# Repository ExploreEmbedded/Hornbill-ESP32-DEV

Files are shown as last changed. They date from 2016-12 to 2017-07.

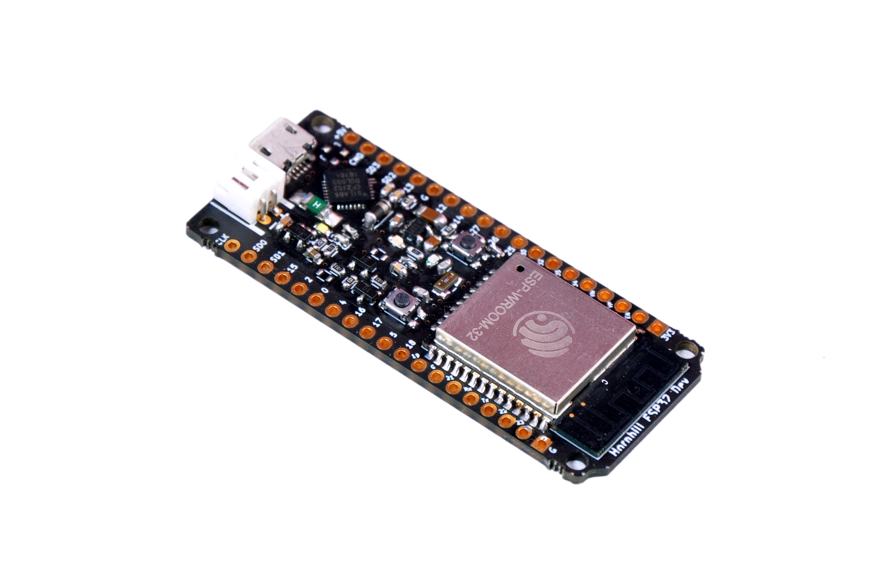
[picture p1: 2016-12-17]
Others/images/Hornbill_02.JPG

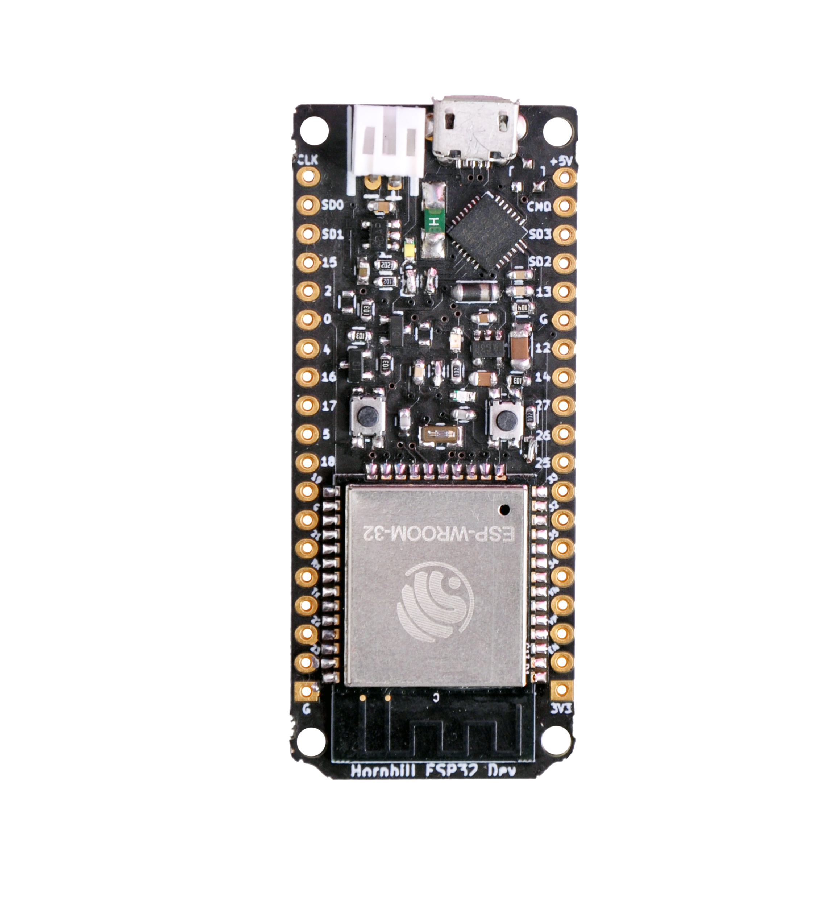
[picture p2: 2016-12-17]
Others/images/Hornbill_01.JPG

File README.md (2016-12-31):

# Hornbill-ESP32-DEV
Affordable, Rugged, Secure and Open Hardware for battery powered connected things with ESP32.
Hornbill ESP32 Dev
Hornbill is based on ESP32. A single chip solution  with  dual core high speed processors, numerous peripherals and built in WiFi and Bluetooth (Classic as well as BLE). Hornbill  ESP32 Dev board comes with built in single cell LiPo charger.  

The project Hornbill will also offer a rugged IP6 water/dust proof case and multipurpose baseboard to build rugged hardware. We will be writing numerous bare metal as well as Arduino tutorials to get you started. 

We believe IoT devices need to be more secure and we will work on providing end to end TLS1.2 encryption with major IoT cloud platforms. We will also on top build Open Source IoT frameworks to provide templates to run your own secure servers!  

We will be crowdfunding the project soon, signup at crowdsupply to get notified when the project goes live.

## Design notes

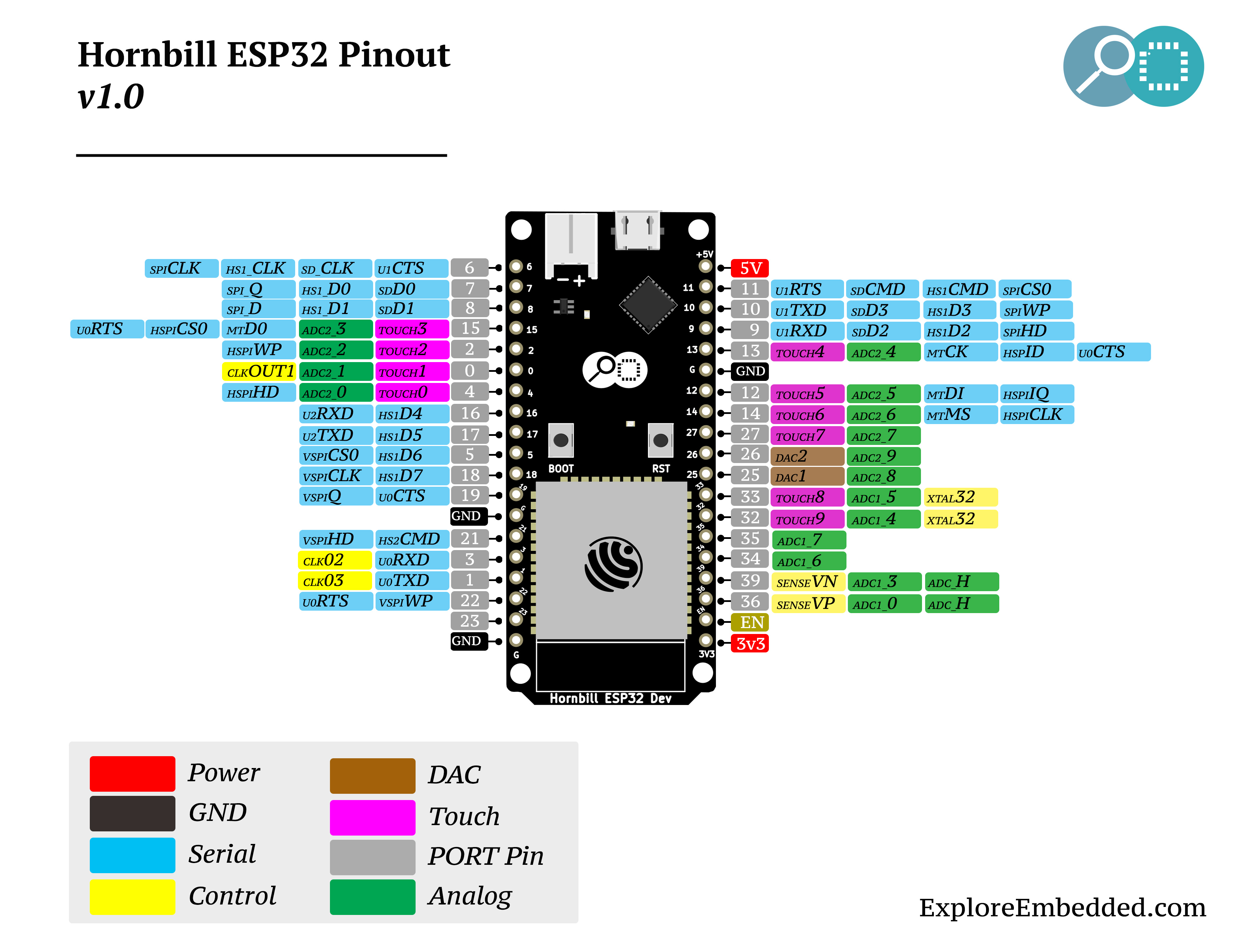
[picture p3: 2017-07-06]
pinout/v1.0/pinout_horbil_v1.0l.jpg

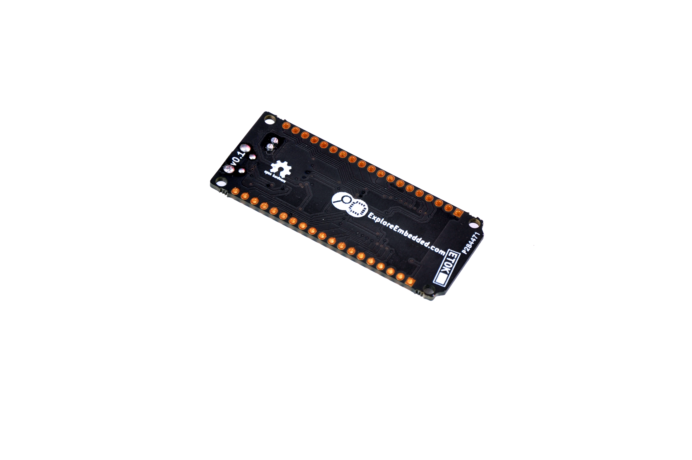
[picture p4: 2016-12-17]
Others/images/Hornbill_03.JPG

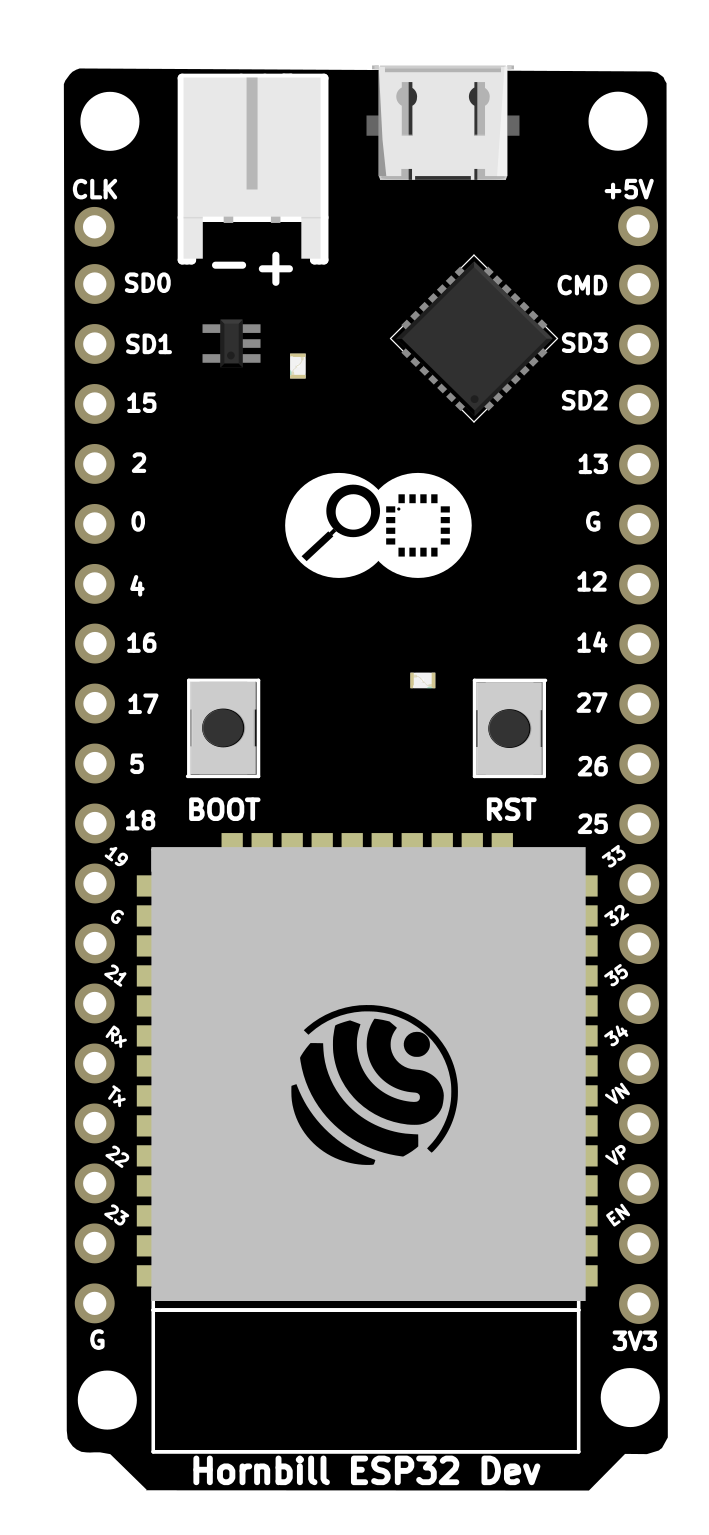
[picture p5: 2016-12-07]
Others/Fritzing/images/HornbillESP32_breadboard.png

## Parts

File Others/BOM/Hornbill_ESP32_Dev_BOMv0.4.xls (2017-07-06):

BOM
Product Name: Hornbill ESP32 Dev
Version:V0.4
Issue Date:13/06/2017
Quantity | 500
Item No. (??) | Reference Des (????) | Qty (??) | Catalog (??) | Part_Description (????) | Part_Value (???) | Part_Package (????) | Manufacturers Name (??????) | Manufacturers Part No. (??????) | Distributors Name (?????) | Distributors Part No. (?????)
1 | R1 | 1 | Resister | RES 100K OHM 1/4W 1% 0603 | 100K | 603
2 | R12,R8,R9,R10,R16,R17 | 6 | Resister | RES 0E OHM 1/4W 1% 0603 | 0E | 603
3 | R13 | 1 | Resister | RES 330E OHM 1/4W 1% 0603 | 330E | 603
4 | R2 | 1 | Resister | RES 2K OHM 1/4W 1% 0603 | 2K | 603
5 | R3,R4 | 2 | Resister | RES 1K OHM 1/4W 1% 0603 | 1K | 603
6 | R5,R6 | 2 | Resister | RES 12K OHM 1/4W 1% 0603 | 12K | 603
7 | R7,R11 | 2 | Resister | RES 10K OHM 1/4W 1% 0603 | 10K | 603
8 | C6,C1 | 2 | Capacitor | CAP CER 4.7UF 25V 10% X7R 0603 | 4.7uF | 603
9 | C2 | 1 | Capacitor | CAP CER 1UF 25V 10% X7R 0603 | 1uF | 603
10 | C5 | 1 | Capacitor | CAP CER 2.2UF 25V 10% X7R 0603 | 2.2uF | 603
11 | C7 | 1 | Capacitor | CAP Tantalum 100UF 25V 10% X7R 1206 | 100uF | 1206/Case 'A'
12 | C8,C10 | 2 | Capacitor | CAP CER 15pF 25V 10% X7R 0603 | 15pF | 603
13 | C9,C3,C4 | 3 | Capacitor | CAP CER 0.1uF 25V 10% X7R 0603 | 0.1uF | 603
14 | P1 | 1 | Connector | JST Connector, Right angle,2mm, White | JST | Surface Mount | JST (JAPAN SOLDERLESS TERMINALS) | S2B-PH-SM4-TB(LF)(SN) | element14 | 9492615
16 | U5 | 1 | IC | IC Bridge Controller CP2104 | CP2102 | QFN-24-1EP 4mmX4mm | Silicon Labs (http://www.digikey.com/en/supplier-centers/s/silicon-labs) | CP2104-F03-GM (http://www.digikey.com/product-detail/en/silicon-labs/CP2104-F03-GM/336-2008-5-ND/2486177) | Digikey | 336-2008-5-ND (http://www.digikey.com/product-detail/en/silicon-labs/CP2104-F03-GM/336-2008-5-ND/2486177)
17 | F1 | 1 | Fuse | Fuse,SMD,0.5A,Very fast blow | SMD Fuse | 1206 | LITTELFUSE (http://in.element14.com/littelfuse) | 0466.500NRHF | element14 | 2679301
18 | D2 | 1 | LED | LED, SMD, Yellow , 0603 | SMD LED | 603
19 | D3 | 1 | LED | LED, SMD, Red , 0603 | SMD LED | 603
20 | D4 | 1 | LED | LED, SMD, Blue , 0603 | SMD LED | 603
21 | IC1 | 1 | IC | Charger , MCP73831, 5pin,SMD | MCP73831 | SOT-23-5
22 | Q1 | 1 | IC | P Channel MOSFET, 3A, 3pin SMD | IRLML5203 | SOT-23
23 | U4 | 1 | Regulator | 3.3V Regulator, 0.6A, LDO | AP2112K-3.3V | SOT-23-5
24 | Q2,Q3 | 2 | Transistor | SMD Transistor, S8050 | S8050 | SOT-23
25 | CON1 | 1 | Connector | Micro USB CONN, 5 pin , | Micro USB
26 | D1 | 1 | Diode | Schottkey Diode | BAT20J |  | STMICROELECTRONICS | BAT20JFILM | element14 | 1467541
27 | SW1,SW2 | 2 | Switch | SWITCH TACTILE SPST-NO 50MA 32V | Tactile Switch | SMD | C&K | KMR731NG LFS | DigiKey
28 | Y1 | 1 | Crystal | 32.768kHz ±20ppm Crystal 12.5pF 70 kOhm -40°C ~ 85°C Surface Mount 2-SMD, No Lead | 32.768KHZ | SMD | Abrocn LLC | ABS07-32.768KHZ-T | DigiKey | 535-9542-2-ND
29 | ESP32 Module | 1 | WiFI | ESP32, WIFI , BLE |  |  | Espressif
1. Recommended Distributor: Digi-Key, Mouser, Avnet Express, Farnell.
2. Catalog: Capacitor,Resister,Diode,Connector,Transistor,IC,PROTECTOR CATEGORY,OTHER
3. Required Fields: Item No, Reference Des, Qty, Catalog, Part_Value, Part Package
Optional Fields: Part_Description, Manufacturers Name, Manufacturers Part No, Distributors Name, Distributors Part No, Unit Cost, Price break to use, Notes/Remark

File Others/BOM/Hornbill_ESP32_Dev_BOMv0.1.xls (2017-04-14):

BOM
Product Name: Hornbill ESP32 Dev
Version:V0.1
Issue Date:16/03/2017
Quantity | 500
Item No. (??) | Reference Des (????) | Qty (??) | Catalog (??) | Part_Description (????) | Part_Value (???) | Part_Package (????) | Manufacturers Name (??????) | Manufacturers Part No. (??????) | Distributors Name (?????) | Distributors Part No. (?????) | Price Break To Use (????????) | Notes/Remark (??)
1 | R15,R14,R1 | 3 | Resister | RES 100K OHM 1/4W 1% 0603 | 100K | 603
2 | R18,R12,R8,R9,R10,R16,R17 | 7 | Resister | RES 0E OHM 1/4W 1% 0603 | 0E | 603
3 | R2 | 1 | Resister | RES 2K OHM 1/4W 1% 0603 | 2K | 603
4 | R3,R4,R13 | 3 | Resister | RES 1K OHM 1/4W 1% 0603 | 1K | 603
5 | R5,R6 | 2 | Resister | RES 12K OHM 1/4W 1% 0603 | 12K | 603
6 | R7,R11 | 2 | Resister | RES 10K OHM 1/4W 1% 0603 | 10K | 603
7 | C6,C1 | 2 | Capacitor | CAP CER 4.7UF 25V 10% X7R 0603 | 4.7uF | 603
8 | C2 | 1 | Capacitor | CAP CER 1UF 25V 10% X7R 0603 | 1uF | 603
9 | C3 | 1 | Capacitor | CAP CER 10UF 25V 10% X7R 1206 | 10uF | 1206
10 | C5 | 1 | Capacitor | CAP CER 2.2UF 25V 10% X7R 0603 | 2.2uF | 603
11 | C7 | 1 | Capacitor | CAP Tantalum 100UF 25V 10% X7R 1206 | 100uF | 1206/Case 'A'
12 | C8,C10 | 2 | Capacitor | CAP CER 15pF 25V 10% X7R 0603 | 15pF | 603
13 | C9 | 1 | Capacitor | CAP CER 0.1uF 25V 10% X7R 0603 | 0.1uF | 603
14 | P1 | 1 | Connector | JST Connector, Right angle,2mm, White | JST | Surface Mount | JST (JAPAN SOLDERLESS TERMINALS) | S2B-PH-SM4-TB(LF)(SN) | element14 | 9492615
15 | P2,P3 | 2 | Pin Headers | 19Pin Male , Single line berg stick | 19 Pin | Through hole
16 | U5 | 1 | IC | IC Bridge Controller CP2104 | CP2102 | QFN-24-1EP 4mmX4mm | Silicon Labs (http://www.digikey.com/en/supplier-centers/s/silicon-labs) | CP2104-F03-GM (http://www.digikey.com/product-detail/en/silicon-labs/CP2104-F03-GM/336-2008-5-ND/2486177) | Digikey | 336-2008-5-ND (http://www.digikey.com/product-detail/en/silicon-labs/CP2104-F03-GM/336-2008-5-ND/2486177)
17 | F1 | 1 | Fuse | Fuse,SMD,0.5A,Very fast blow | SMD Fuse | 1206 | LITTELFUSE (http://in.element14.com/littelfuse) | 0466.500NRHF | element14 | 2679301
18 | D2 | 1 | LED | LED, SMD, Yellow , 0603 | SMD LED | 603
19 | D3 | 1 | LED | LED, SMD, Red , 0603 | SMD LED | 603
20 | D4 | 1 | LED | LED, SMD, Yellow , 0603 | SMD LED | 603
21 | IC1 | 1 | IC | Charger , MCP73831, 5pin,SMD | MCP73831 | SOT-23-5
22 | Q1 | 1 | IC | P Channel MOSFET, 3A, 3pin SMD | IRLML5203 | SOT-23
23 | U4 | 1 | Regulator | 3.3V Regulator, 0.6A, LDO | AP2112K-3.3V | SOT-23-5
24 | Q2,Q3 | 2 | Transistor | SMD Transistor, S8050 | S8050 | SOT-23
25 | CON1 | 1 | Connector | Micro USB CONN, 5 pin , | Micro USB
26 | D1 | 1 | Diode | Schottkey Diode | BAT20J |  | STMICROELECTRONICS | BAT20JFILM | element14 | 1467541
27 | SW1,SW2 | 2 | Switch | SWITCH TACTILE SPST-NO 50MA 32V | Tactile Switch | SMD | C&K | KMR731NG LFS | DigiKey
28 | Y1 | 1 | Crystal | 32.768kHz ±20ppm Crystal 12.5pF 70 kOhm -40°C ~ 85°C Surface Mount 2-SMD, No Lead | 32.768KHZ | SMD | Abrocn LLC | ABS07-32.768KHZ-T | DigiKey | 535-9542-2-ND
 | ESP32 Module | 1 | WiFI | ESP32, WIFI , BLE |  |  | Espressif
34
35
36
37
38
39
40
41
42
43
44
45
1. Recommended Distributor: Digi-Key, Mouser, Avnet Express, Farnell.
2. Catalog: Capacitor,Resister,Diode,Connector,Transistor,IC,PROTECTOR CATEGORY,OTHER
3. Required Fields: Item No, Reference Des, Qty, Catalog, Part_Value, Part Package
Optional Fields: Part_Description, Manufacturers Name, Manufacturers Part No, Distributors Name, Distributors Part No, Unit Cost, Price break to use, Notes/Remark

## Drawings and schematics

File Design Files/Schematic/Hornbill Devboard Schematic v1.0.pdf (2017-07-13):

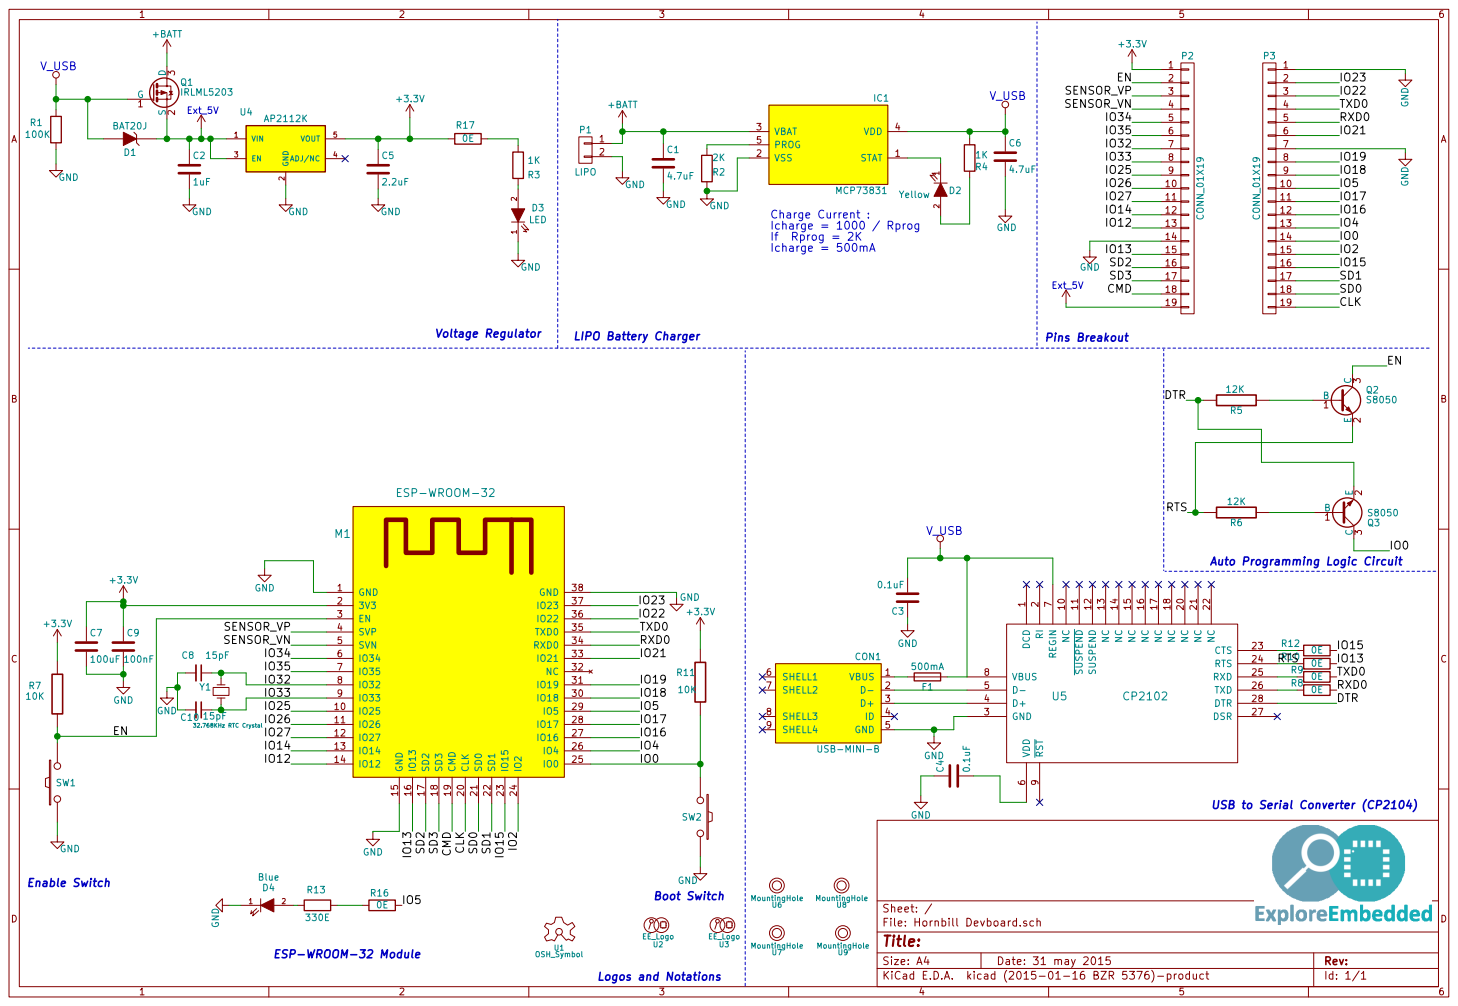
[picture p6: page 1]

2 EN 3 ADJ/NC 4 VOUT 5 U4 AP2112K GND

1 2 D2 Yellow GND Charge Current :

Auto Programming Logic Circuit

9 NC 10 NC 20 SUSPEND 11 NC 21 SUSPEND 12 NC 22 NC 13 CTS 23 NC 14 RTS 24 NC 15 RXD 25 NC 16 TXD 26 NC 17 DSR 27 NC 18 DTR U5 CP2102 28 R9 0E R8 0E R10 0E R12 0E RXD0 TXD0

USB to Serial Converter (CP2104)

Id: 1/1 Title: File: Hornbill Devboard.sch Sheet: /

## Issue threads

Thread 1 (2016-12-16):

Modification needs to be done

raghavendrahassy, 2016-12-16:
1. Switches names are not displayed.
2. Board name should be inside the board.
3. Clearance between JST conn and USB.
4. Fuse footprint needs to be changed.

sharanago, 2017-04-08:
Changes done

Closed 2017-04-08.

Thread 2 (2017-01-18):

Modifications -- 2

raghavendrahassy, 2017-01-18:
Following changes needs to be done for v0.2

1. Stable power circuit.
2. Replace from CP2102 to CP2104.
3. All the broken pins legend should be as per Hornbill ESP32 Proto.

sharanago, 2017-04-08:
Changes done

Closed 2017-04-08.

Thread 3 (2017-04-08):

Pre-final modifications

raghavendrahassy, 2017-04-08:
1. Onboard LED should be connected to GPIO5 with 330E Resistor in series.
2. Change CP2104 to CP2102  USB to Serial bridge.

sharanago, 2017-04-08:
1. LED connected to GPIO5
2. Changed to CP2102

Closed 2017-04-08.

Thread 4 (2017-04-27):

VCC(5V) and 3.3V tracks got short

raghavendrahassy, 2017-04-27:
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

sharanago, 2017-05-01:
Solved the issue

Closed 2017-05-01.

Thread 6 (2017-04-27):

Charging ic (MCP73831) getting hot

raghavendrahassy, 2017-04-27:
@ LIPO battery Charging ic (MCP73831) getting hot.
Following changes needs to be done for layout is used as heat sink.
1. Copper pad should be thick.
2. add many vias for heat to dissipate.
3. Cin and Cout cap. should be placed closer to pin.
 Check the below image.
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

sharanago, 2017-05-01:
Charger circuit layout changed as suggested. Verify if any changes.

Closed 2017-05-01.

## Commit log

2016-12-07 Design Files added
    [Hornbill Devboard.kicad_pcb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]
2017-01-21 Changes done as per Issues
    [Hornbill Devboard.kicad_pcb, Hornbill Devboard.sch]
2017-01-25 Legends as per base board
    [Hornbill Devboard.kicad_pcb]
2017-01-27 Changed to smd JST connector
    [Hornbill Devboard.kicad_pcb, _saved_Hornbill Devboard.sch]
2017-01-27 Power LED direction changed
    [Hornbill Devboard.kicad_pcb]
2017-02-03 Added battery monitoring Circuit
    [Hornbill Devboard.kicad_pcb, Hornbill Devboard.sch, _saved_Hornbill Devboard.sch]
2017-02-03 Gerber fiel
    Added Gerber fiel and mechanical holes
    [Hornbill Devboard-B_Cu.gbr, Hornbill Devboard-B_Mask.gbr, Hornbill Devboard-B_SilkS.gbr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]
2017-04-08 Chnged to CP2102 and LED to IO5
    [Hornbill Devboard.kicad_pcb, Hornbill Devboard.sch]
2017-04-10 BOM v0.1 added
    [Hornbill_ESP32_Dev_BOMv0.1.xls]
2017-04-10 v0.3 Modified
    [Hornbill Devboard.kicad_pcb, Hornbill Devboard.sch]
2017-04-10 v0.3 Changes1
    [Hornbill Devboard.kicad_pcb, Hornbill Devboard.sch]
2017-04-12 Gerber files generated for v0.3
    [Hornbill Devboard-B_Cu.gbr, Hornbill Devboard-B_Mask.gbr, Hornbill Devboard-B_SilkS.gbr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]
2017-04-14 BOM modified
    [Hornbill_ESP32_Dev_BOMv0.1.xls]
2017-04-27 removed short track
    [Hornbill Devboard.kicad_pcb, Hornbill Devboard.sch]
2017-05-01 Charger Layout changed
    [Hornbill Devboard.kicad_pcb]
2017-05-01 Gerber fiel generated for v0.4
    [Hornbill Devboard-B_Cu.gbr, Hornbill Devboard-B_Mask.gbr, Hornbill Devboard-B_SilkS.gbr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]
2017-05-11 Final Version
    [Hornbill Devboard.kicad_pcb]
2017-07-06 Version Updated
    [Hornbill Devboard.kicad_pcb]
2017-07-06 pinout changed as per v1.0
    [Hornbill_ESP32_Dev_BOMv0.4.xls]
2017-07-13 Schematic updated
